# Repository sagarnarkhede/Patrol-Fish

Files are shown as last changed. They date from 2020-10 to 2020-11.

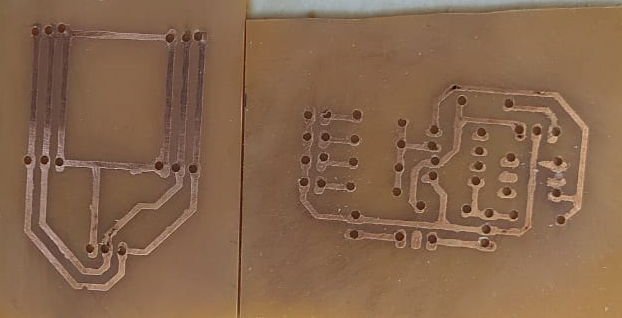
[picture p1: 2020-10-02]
Photos/Buoys_PCB.png

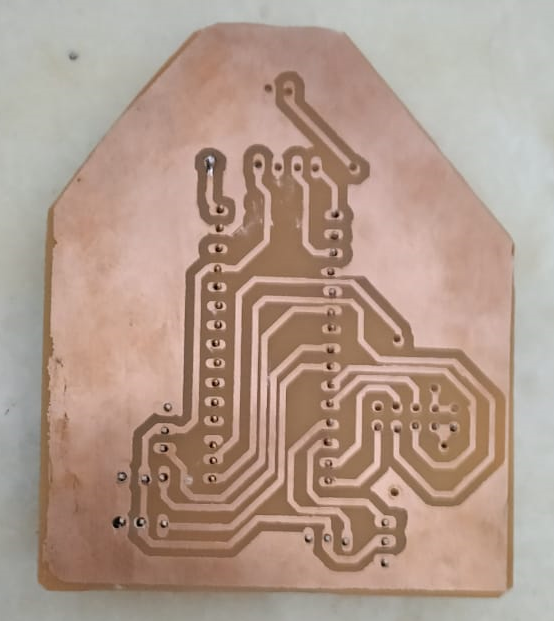
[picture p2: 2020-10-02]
Photos/PatrolFishp_PCB.png

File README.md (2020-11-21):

# Patrol-Fish
This is the theme of eYantra Robotics Competition 2019-20 held at IIT Bombay.The project was based on various skills like 3D Modelling of Fish, Wireless Communication,Waterproofi ng, programing of arduino etc I was participated in this competition and I worked as a team leader of our team. and we got rank 3.

<!--
## Team Members:-
### 1) [Sagar S Narkhede](https://www.linkedin.com/in/sagar-narkhede-5bb944195/)(Team Leader)
### 2) [Omkar Sutar](https://www.linkedin.com/in/omkarsutar8991/)
### 3) [Ashlesha Borade](https://www.linkedin.com/in/ashlesha-borade-719434162/)
### 4) [Pooja Katkar](https://www.linkedin.com/in/pooja-katkar-a85b6b137/)

-->

## Videos:-

[Final demostratio video](https://youtu.be/UlDN9iitq78)

[3D animation](https://youtu.be/h_NEuzW5vi0)

[theme intro](https://youtu.be/WjUetfCpf9E)

[progress video](https://youtu.be/jCL4euYWsCw)

[buyo testing](https://youtu.be/ekcvl8QJEpc)

[joystick testing](https://youtu.be/XAv6_P2s71k)

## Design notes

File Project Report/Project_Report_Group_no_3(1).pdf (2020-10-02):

A

## Project Report

On

# Aquatic FishRobo

### Guided by

Dr.N.P.Futane

### Submitted By

### 1. Sagar Sopan Narkhede (17231014) 2. Omkar Gorakhnath Sutar (16132063) 3. Pooja Kisan Katkar(17231011) 4. Ashlesha Maruti Borade (16131036)

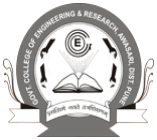
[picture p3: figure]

Department of Electronics and Telecommunication Engineering

## GOVT. COLLEGE OF ENGINEERING AND RESEARCH

## AWASARI (KHURD), DIST- PUNE 412405

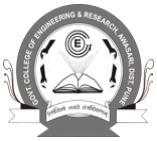
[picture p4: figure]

# CERTIFICATE

## This is to certify that following students of B.E. (Electronics and

## Telecommunication), have done bonafide work on the project stage-I

entitled – “AQUATIC FISHROBO”.

## They are allowed to submit this work to the Savitribai Phule Pune

## University towards partial fulfilment of the requirement for the award

## of Bachelor of Engineering (Electronics and Telecommunication)

during the year 2019-2020.

### 1. Sagar Sopan Narkhede (17231014) 2. Omkar Gorakhnath Sutar (16132063) 3. Pooja KisanKatkar (17231011) 4. Ashlesha Maruti Borade (16131036)

Project Guide | Head of Dept. | Principal
(Dr. N.P. Futane) | (Dr.M.S. Nagmode) | (Dr. A.S. Pant)

## INDEX

Sr. No | Table of contents | Page No
1 | Abstract | 4
2 | Introduction | 5
3 | Literature review | 7
4 | Hardware | 9
| 1.Electronic System | 10
| 2.Mechanical system | 15
5 | Joystick | 17
6 | PCB fabrication | 18
7 | Software | 21
8 | Algorithm | 23
9 | Flowchart | 24
10 | Program | 25
11 | Cost Estimation | 26
12 | Advantages | 27 28
13 | Applications
14 | Future scope | 28
15 | Conclusion | 29

ABSTRACT

In the Swachh Ganga mission getting data about the health of the water body, i.e. the

measurement of concentration of impurities, temperature etc is essential for creating a more

effective plan of action. In this project we unleash our imagination and discover our talent in

3D designing to build a bio-inspired fish robot that is capable of traversing in water to collect

data about a water-body's health and transmit it to a buoy. Challenges in this project include:

3D designing and fabrication, PCB designing, Microcontroller programming, wireless

communication etc.

INTRODUCTION

- The Ganges (or Ganga), the largest river in India, provides water to about 40% of

India's population across 11 states, serving an estimated population of 500 million

people with more than any other river in the world.

- But this source of life now severely polluted with human waste and industrial

contaminants, poses significant threats to human health and the larger environment.

- As engineers , what can we do to help in the Swachh Ganga mission. We know,

monitoring the state of a system is an essential part of trying to get it to a desired

target

- . In the Swachh Ganga mission getting data about the health of the water body, i.e. the

measurement of concentration of impurities, temperature etc is essential for creating a

more effective plan of action.

- In this project we unleash our imagination and discover our talent in 3D designing to

build a bio-inspired fish robot that is capable of traversing in water to collect data

about a water-body's health and transmit it to a buoy.

- Challenges in this project include: 3D designing and fabrication, PCB designing,

Microcontroller programming, wireless communication etc.

- In this project, the Aquatic Robot designed by the us needs to swim through a defined

course and trigger “Anchored Buoys” on its way. The course is defined by the

position and orientation of“Gateways”. We also designed a wireless joystick to

control the Aquatic Robot.

### Arena Configuration:

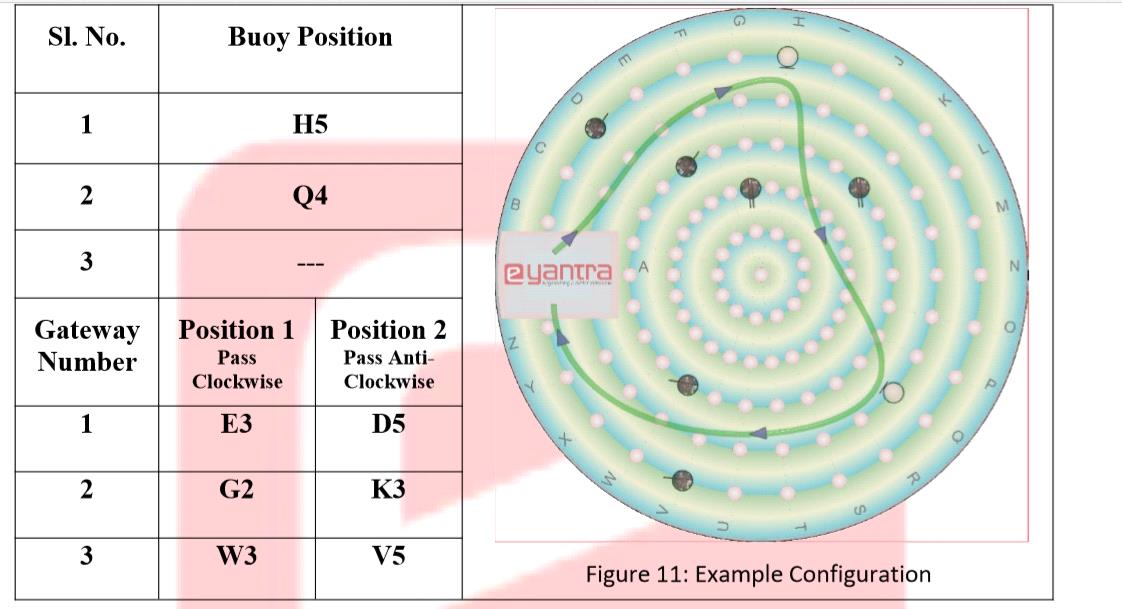
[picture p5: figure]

Figure: Arena Configuration.

LITERATURE REVIEW

The Ganges (or Ganga), the largest river in India, provides water to about 40% of

India's population across 11 states, serving an estimated population of 500 million people

with more than any other river in the world. But this source of life now severely polluted with

human waste and industrial contaminants, poses significant threats to human health and the

larger environment. As engineers , what can we do to help in the Swachh Ganga mission. We

know, monitoring the state of a system is an essential part of trying to get it to a desired

target. In the Swachh Ganga mission getting data about the health of the water body, i.e. the

measurement of concentration of impurities, temperature etc is essential for creating a more

effective plan of action. In this theme we unleash our imagination and discover our talent in

3D designing to build a bio-inspired fish robot that is capable of traversing in water to collect

data about a water-body's health and transmit it to a buoy. We divide the Project into a

number of tasks to build the Aqaurit Robot in a step- by-step manner making the process

more interesting for us. Challenges in this Project include: 3D designing and fabrication, PCB

designing, Microcontroller programming, wireless communication etc. We tiik inspiration

from the variety of fishes in the aquatic world and created the locomotion of that fish while

designing their robot. After building the bot,we need to navigate it in an arena.

The reference used for the microntroller boards and their specifications are:

- Arduino Nano (ATmega328)

The Arduino Nano is a small, complete, and breadboard-friendly board based on the

ATmega328P; it offers the same connectivity and specs of the Arduino Uno board in a

smaller form factor.[1][2] The Arduino Nano is programmed using the Arduino Software

(IDE), Arduino.cc's Integrated Development Environment common to all our boards and

running both online and offline.

- Arduino Nano(ATmega328P) technical specification
SRNO | COMPONENT | SPECIFICATION
1 | Microcontroller: | ATmega328
2 | Architecture: | AVR
3 | Operating Voltage: | 5 V
4 | Flash Memory | 32 KB of which 2 KB used by bootloader
5 | SRAM | 2 KB
6 | Clock Speed | 16 MHz
7 | Analog IN Pins | 8
8 | EEPROM | 1 KB
9 | DC Current per I/O Pins | 40 mA (I/O Pins)
10 | Input Voltage | 7-12 V
11 | PWM Output | 6
12 | Power Consumption | 19 mA
13 | PCB Size | 18 x 45 mm

HARDWARE

❖ ROBOT

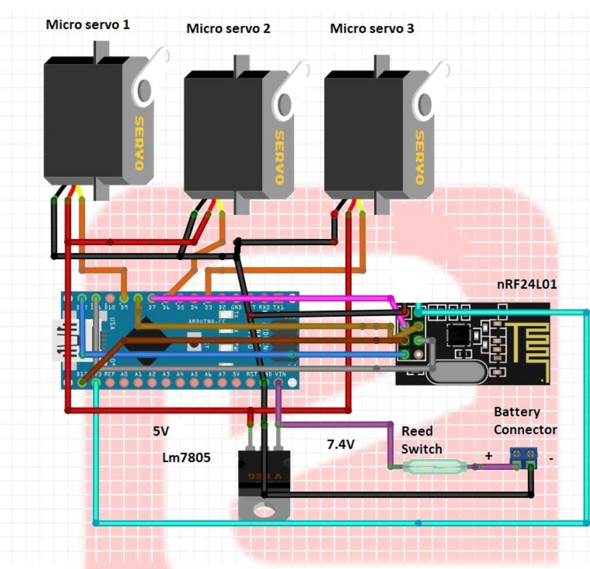
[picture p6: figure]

1.Electronic system:

### 1.1 Arduino Nano 328

The controller performs the various controlling actions & manages communication between

different units of system like sensors, actuators, motor driver, etc. for data analysis & further

operation.

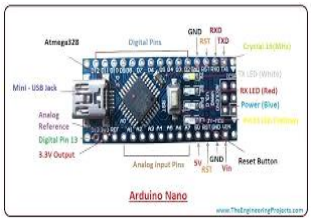
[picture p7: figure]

### 1.2 Joystick:

We have designed the joystick module to control the Aquatic Robot wirelessly.

Grove - Thumb Joystick is a Grove compatible module which is very similar to the 'analog'

joystick on PS2(PlayStation 2) controllers. The X and Y axes are two ~10k potentiometers

which control 2D movement bygenerating analog signals. The joystick also has a push button

that could be used for special applications.

When the module is in working mode, it will output two analog values, representing two

directions.Compared to a normal joystick, its output values are restricted to a smaller range

(i.e. 200~800), only when pressed that the X value will be set to 1023 and the MCU can

detect the action of pressing

1.3Servo Motor:

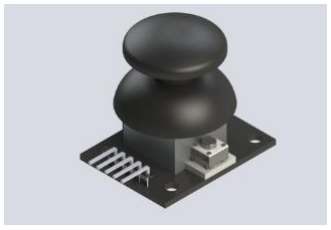
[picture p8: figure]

A servomotor is a rotary actuator or linear actuator that allows for precise control of angular

or linear position, velocity and acceleration. It consists of a suitable motor coupled to a sensor

for position feedback. It also requires a relatively sophisticated controller, often a dedicated

module designed specifically for use with servomotors.

Using these Servo motors we will give motion to our Aquatic Robot like fish.

The Towerpro MG90S Mini Digital Servo is 360° rotation servo. It is a Digital Servo Motor

which receives and processes PWM signal faster and better. It equips sophisticated internal

circuitry that provides good torque, holding power, and faster updates in response to external

forces.The good optimized performance and reliability of our servos have made them the

favourite choice of many RC hobbyists.

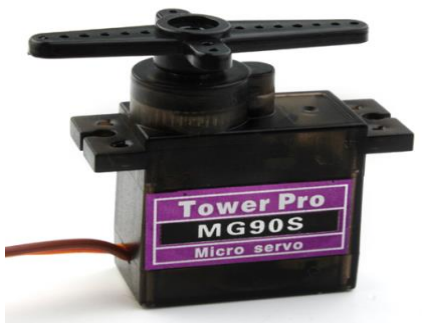
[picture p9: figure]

### 1.4 Li-ion Battery (2200 mAh, 11V):

To supply the power for the different units of the robot.This battery pack is made up of best

quality tested ICR 18650 2000mAh 20C Lithium-Ion Batteries and BMS circuit. It is small

in size and weight compared to Ni-Cd, Ni-MH, and Lead Acid Batteries. With the inbuilt

Charge protection circuit, the battery pack can be directly charged with the DC power

Adapter, so need not use the specialized battery chargers and worry about overcharging.

We build these battery packs in diverse range to fulfil 7.4V to 14.8 V and differential

capacity requirement. This battery pack is very convenient to recharge and install in your

project requirement with 5mm DC female jack for changing and Nylon Female T-connector

for discharging or connecting to your applications.

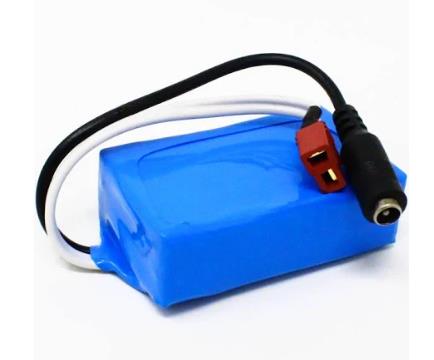
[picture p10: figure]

### 1.5 NRF24L01 Transceiver

The nRF24L01+ is a single chip 2.4GHz transceiver with an embedded baseband protocol

engine (Enhanced ShockBurstTM), suitable for ultra low power wireless applications. The

nRF24L01+ is designed for operation in the world wide ISM frequency band at 2.400 -

2.4835GHz. You can operate and configure the nRF24L01+ through a Serial Peripheral

Interface (SPI). The register map, which is accessible through the SPI, contains all

configuration registers in the nRF24L01+ and is accessible in all operation modes of the chip.

The radio front end uses GFSK modulation. It has user configurable parameters like frequency channel, output power and air data rate. nRF24L01+ supports an air data rate of

250 kbps, 1 Mbps and 2Mbps. The high air data rate combined with two power saving modes

make the nRF24L01+ very suitable for ultra low power designs.nRF24L01+ is drop-in

compatible with nRF24L01 and on-air compatible with nRF2401A, nRF2402, nRF24E1 and

nRF24E2. Intermodulation and wideband blocking values in nRF24L01+ are much improved

in comparison to the nRF24L01 and the addition of internal filtering to nRF24L01+ has

improved the margins for meeting RF regulatory standards. Internal voltage regulators ensure

a high Power Supply Rejection Ratio (PSRR) and a wide power supply range.

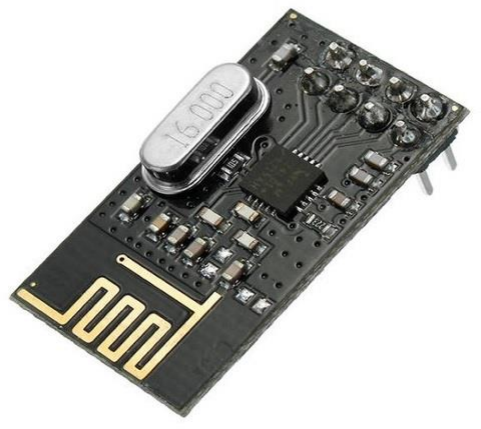
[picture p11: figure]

### 1.6 Reed Switch:

This is a small device called a reed switch. When the device is exposed to a magnetic

field, the two ferrous materials inside the switch pull together and the switch closes.

When the magnetic field is removed, the reeds separate and the switch opens. This makes

for a great non-contact switch. This switch can carry up to 1.2A.

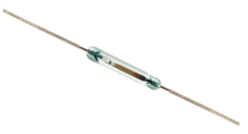
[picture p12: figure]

### 1.7 Hall Effect Sensor:

A Hall effect sensor is a device that is used to measure the magnitude of a magnetic

field. Its output voltage is directly proportional to the magnetic field strength through

it.Hall effect sensors are used for proximity sensing, positioning, speed detection, and

current sensing applications.Frequently, a Hall sensor is combined with threshold

detection so that it acts as and is called a switch. They can also be used in computer

keyboards, an application that requires ultra-high reliability. Another use of a Hall

Sensor is in the creation of MIDI organ pedal-boards, where the movement of a 'key'

on the pedal-board is translated as an on/off switch via Hall Sensors.

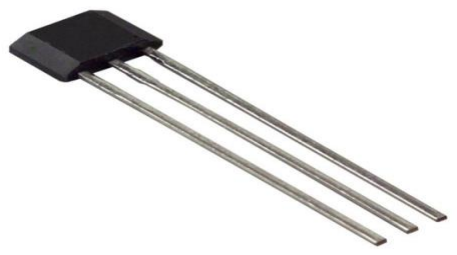
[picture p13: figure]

2.Mechanical system

### 2.1 Servo Motor:

Servo motor is used for giving "S" motion to the fish Robot. There are 5 Servo motor used

1.Head Servo: which will control middle part.

2.Two Fin Servo: To control Fin motion

Middle Servo: To control second part

Tail Servo: To control Tail of the Fish

2.2 3D Printed Fish:

It is the hardware body structure of the robot to constrain all the components required for the

robot. For the fabrication of Nylon 6 (PA6/66)

A filament that is ideal for more experienced users of 3D printers. Nylon is strong and

durable. Nylon can be used as flexible hinge when printed thinly or can be strong enough to

use for engineering applications such as gears due to low friction qualities and where subject

to low force loadings. A heated print bed is recommended when printing with Nylon to

prevent warping. Our Nylon is made using the purest raw materials without fillers. Our

crosssectional roundness is consistent throughout the whole spool to ensure that a reliable

printing experience is achieved over repeated prints. Our filaments are free from air bubbles

or voids that help to ensure accurate and high definition printing results.

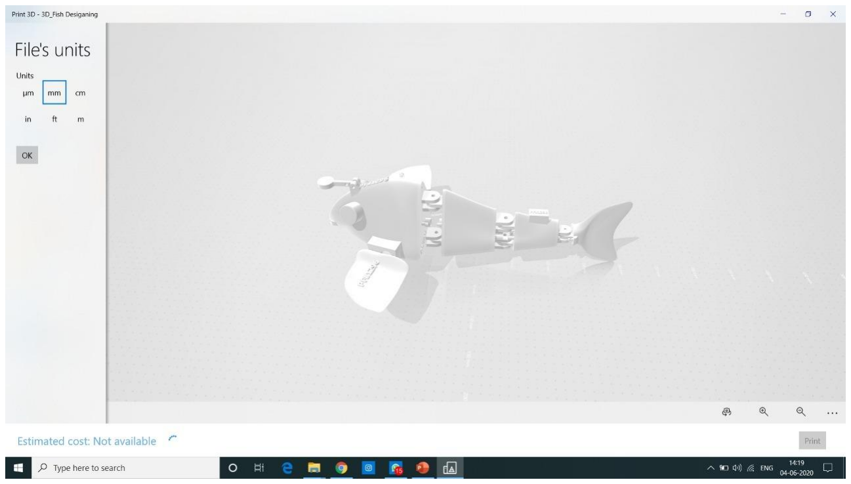
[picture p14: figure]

2.3Gateways:

The pair of objects that the Aquatic Fish Robot needs to go through in the assigned sequence

and also in the direction specified. Dimension of the cylinder are 70mm ± 5mm in diameter

and 170mm in height.

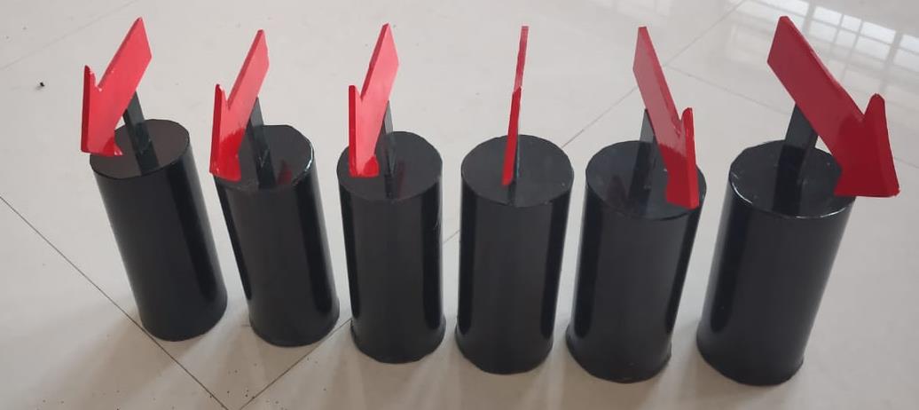
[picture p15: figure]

### 2.4 Anchored Buoys:

The object the Aquatic Fish Robot needs to trigger. The Anchored Buoy is a structure to be placed on

the floor of the pool.The structure has two major parts: Tower that indicate when the Patrol Fish robot

triggers | the | sensor. | The | dimension | of | the | cylinder | of the | Buoy | is | 70mm | ±

5mmindiameterand170mminheight.A circuit board in the tower of the buoy has a latch circuit that

switches the LEDs ON as soon as hall effect sensors senses the field of the magnet on the Patrol Fish

and leaves it on for the rest of the run.

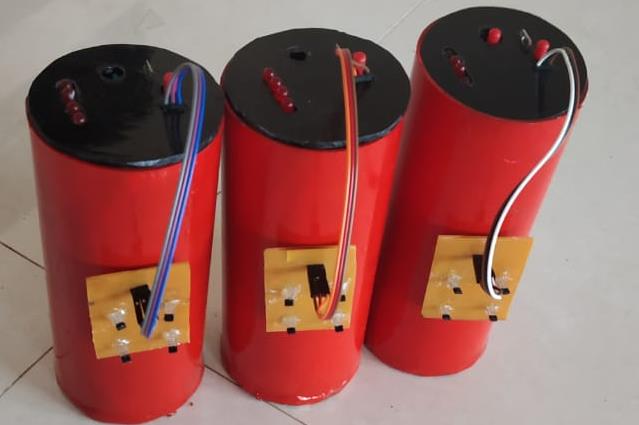
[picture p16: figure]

JOYSTICK

- Description:

1.PCB design forWireless Joystick and hall effect sensor:

We have designed a PCB for Wireless Joystick in Eagle software.

Required Hardware for Wireless Joystick:

1. ArduinoNanoboard
2. NRF24L01Transceiver
3. Joystickmodule
4. Connectors

Joystick module

The Joystick is nothing but two potentiometers that allow us to measure the movement of the

stick in 2-D. Potentiometers are variable resistors and, in a way, they act as sensors providing

us with a variable voltage depending on the rotation of the device around its shaft.(source)

Buzzer:

Buzzer Module for Arduino is an audio signaling device. Buzzer rings out as long as it

receives signal in its data pin.

- Connecting Hardware for Wireless Joystick (Transmittersystem):

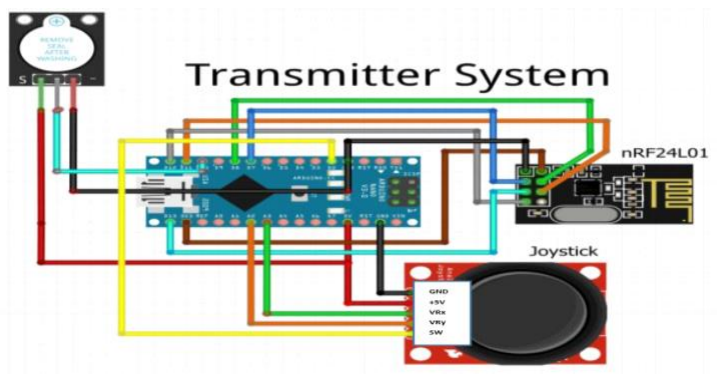
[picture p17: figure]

Figure: Transmitter System connections

PCB FABRICATION

Printed Circuit Board(PCB)

PCB are mainly classified into two types:

Through Hole : Through-hole technology is the process by which component leads

are placed into drilled holes on a bare PCB. Through-hole components are best used for

high-reliability products that require stronger connections between layers.

Surface mount: In Surface Mount Technology components are secured only by

solder on the surface of the board. An SMT component is usually smaller than its through-

hole counter part because it has either smaller leads or no leads at all.

- PCB fabrication.

Step1: Printing the board design file:

After completion of PCB board design file, from board file open visibility settings

by clicking on the button on the top left of the screen. Make only the “Bottom”,

“Pads” and “Dimension” layers visible and hide all other layers

Step2: Toner Transfer:

Cut the copper clad of the approximate size of your board file. Place the printed

photographic paper on copper clad and start pressing it with a heated iron

Step3: Etching process:

Take water in a small plastic container. Add small amount of ferrous chloride

solution to it. Place the toned board in the solution as Stir the board in the

solution.Untoned part will start etching.

Step4:Cleaning:

After etching wash the board with water. Use acetone to remove the toned paper and

marker pen ink

Step5:Drilling:

Drill the holes for pads

Step6: Testing:

Check the continuity test of all the tracks by mustimeter. Removetheshortedtracks.

Step7: Soldering:

Place the component at the top board of the board and start soldering it to the

track with solder wire.

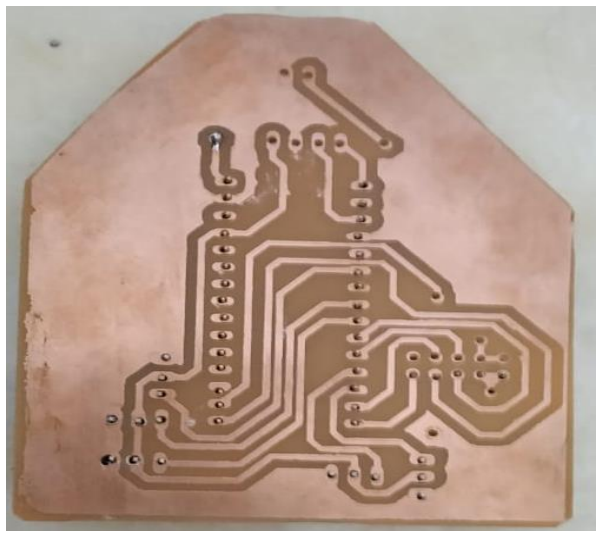
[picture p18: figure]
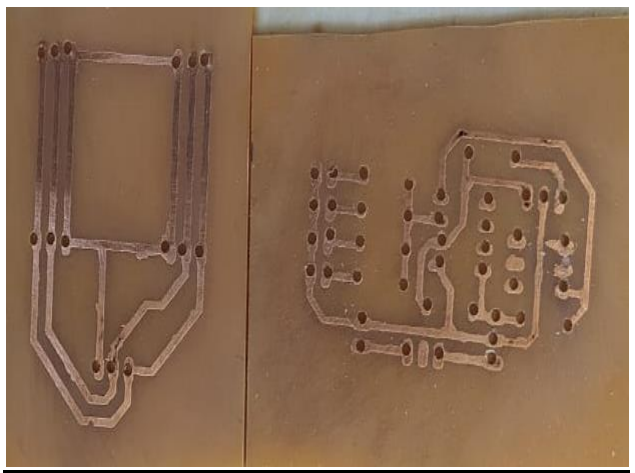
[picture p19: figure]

- Waterproofing:

1.Waterproofing the Fish Body:

Waterproofing of the joints of the Fish body is done by using,

1.Candle Wax

2.Balloons

3.Silicone Gel

### 2. Waterproofing the Elctronic Components:

1. Nail Polish Coating
2. Silicone paste/Adhesive

SOFTWARE

- Blender:

Blender is the free and open source 3D creation suite. It supports the entirety of the 3D

pipeline—modeling, rigging, animation, simulation, rendering, compositing and motion

tracking, even video editing and game creation. Advanced users employ Blender’s API for

Python scripting to customize the application and write specialized tools; often these are

included in Blender’s future releases. Blender is well suited to individuals and small studios

who benefit from its unified pipeline and responsive development process.

- Arduino IDE:

The Arduino Integrated Development Environment (IDE) is a cross-platform application (for

Windows, macOS, Linux) that is written in functions from C and C++. The Arduino IDE

supplies a software library from the Wiring project, which provides many common input and

output procedures. User-written code only requires two basic functions, for starting the sketch

and the main program loop, that are compiled and linked with a program stub main() into an

executable cyclic executive program with the GNU toolchain, also included with the IDE

distribution..

- Autodesk Fusion 360:

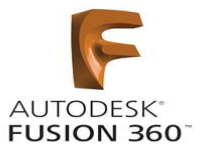
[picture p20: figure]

Fusion 360 is a cloud-based 3D CAD, CAM & CAE design tool from Autodesk. It is

available on a number of platforms including Windows, Mac & In-Browser. It is

functionally similar to other 3D software like Solidworks, Siemens NX, Inventor or Catia.

It is a very full featured program and is available to hobbyists and start-up businesses for

no cost.

- Eagle:

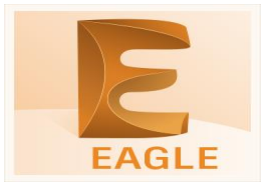
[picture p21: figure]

Acronym for Easily Applicable Graphical Layout Editor, is a design software by Cadsoft

Computers. It is widely used by educationalists, students, hobbyists and professionals

because of its rich yet simple interface with large component library cross-platform support

on Windows, Mac and Linux too! EAGLE is a scriptable electronic design

automation (https://en.m.wikipedia.org/wiki/Electronic_design_automation) (EDA) application with schematic capture, (https://en.m.wikipedia.org/wiki/Schematic_capture) printed circuit

board (https://en.m.wikipedia.org/wiki/Printed_circuit_board) (PCB) layout, (https://en.m.wikipedia.org/wiki/PCB_layout) auto-router (https://en.m.wikipedia.org/wiki/Auto-router) and computer-aided manufacturing (https://en.m.wikipedia.org/wiki/Computer-aided_manufacturing) (CAM) features.

ALGORITHM

1.Start

2. Trigger the Aquatic Robot using Magnet .It will turn the Robot on.
3. Now turn the Joystick too.
4. Establish the NRF Connections Properly and indicate it by glowing LED on Joystick.
5. Use Joystick to Send the Character Massage to NRF Reciever with the Encoded Servo

Action.

6. After receiving the Text properly servo motor will move as per given angle in the Script.
7. Each Joystick value of X and Y will give each servo different Angles and Fish will get its

motion.

8. .Using the Joystick Control the Fish in Water.

9.Pass the Robot safely through the the Gateways.

10. Trigger the Boys with the Magnet on the Robot using Hall effect Sensor.
11. Repeat 9 and 10 until Robot reaches at the Start point again.
12. End

FLOWCHART

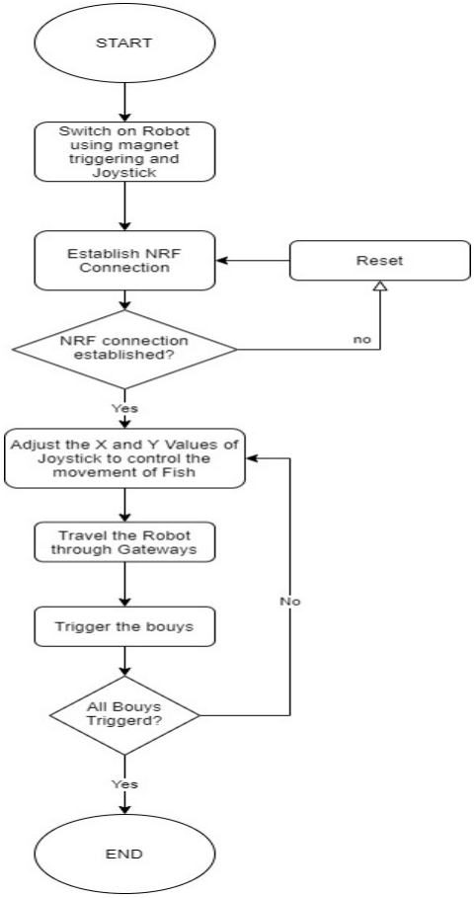
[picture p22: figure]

PROGRAM

### https://drive.google.com/drive/folders/1aHHeiEQJljIpSD1Fyj1P6sBwNRnK6c_

_?usp=sharing (https://drive.google.com/drive/folders/1aHHeiEQJljIpSD1Fyj1P6sBwNRnK6c__?usp=sharing)

COST ESTIMATION

Sr No . | Name of Components | Quantity | Unit Cost(Rs) | Total
1 | Arduino Nano (ATmega 328 Controller) | 2 | 1563 | 1563
2 | NRF24L01 | 2 | 220 | 440
3 | Joystick Module | 1 | 75 | 75
4 | Buzzer Module | 2 | 20 | 40
5 | Servo Motor | 5 | 195 | 975
6 | Battery(5V) | 4 | 25 | 100
7 | Battery(9V) | 2 | 470 | 940
8 | Reed Switch | 1 | 15 | 15
9 | Slide Switch | 3 | 64 | 192
10 | Magnet | 2 | 15 | 30
11 | Push Button | 7 | 15 | 105
12 | Timer IC555 | 3 | 225 | 675
13 | Hall Effect Sensor | 27 | 20 | 540
14 | LEDs | 20 | 5 | 100
15 | Capacitors | 10 | 5 | 50
16 | Resistors | 10 | 3 | 30
17 | Programming cable | 2 | 180 | 360
18 | IC7805 | 2 | 12 | 24
19 | IC7809 | 2 | 12 | 24
20 | IC7812 | 1 | 12 | 24
21 | Water Pool | 1 | 1500 | 1500
22 | Arena | 1 | 1300 | 1300
23 | 3D Printing material | 1kg | 1400 | 1400
| Total | | | 10502

ADVANTAGES

- Aquatic Robots are used for research about animals and underwater wildlife.
- Underwater Exploratory Robots can go underwater longer and deeper than humans
- Robots are less likely to get hurt or die on any missions.
- Exploratory robots can gain information that we can’t physically obtain.

FUTURE SCOPE AND APPLICATIONS

1. Submarine wireless communication.
2. 3D Game Design Platform.
3. Creating Animated movies.
4. Macrolevel Research on Aquatic life and habitat.

CONCLUSION

The project “Aquatic Fish Robot” includes the implementation bio-inspired robot that is

capable of traversing in water .This project includes the implementation of various concepts in

real time based applications like 3D gaming, 3D animation . The project presents a complete

3D non-linear dynamic model of a biomimetic robotic fish. In this project we done with 3D

designing and fabrication, PCB designing and fabrication, Microcontroller programming,

wireless communication etc.

REFERENCES

- eYANTRA Sponsored by MHRD (https://mhrd.gov.in/hi/node/2356) under the National Mission on Education through

ICT (https://mhrd.gov.in/technology-enabled-learning-0) program. An initiative by IIT Bombay that aims to create the next generation of

embedded systems engineers with a practical outlook to help provide practical

solutions to some of the real world problems.

https://www.e-yantra.org

- Autodesk Fusion 360 Tutorials:

https://www.autodesk.in/products/fusion-360/learn-support

- Languages :

Arduino IDE: https://www.arduino.cc/en/Tutorial/HomePage?from=Main.Tutorials

- https://easyengineering.net/microprocessor-and-microcontroller-system-by-godse/
- Book on Programming and Interfacing ATMEL's AVRs
•
- Software source

Audesk Fusion 360:

https://www.autodesk.in/campaigns/education/fusion-360?mktvar002=3510851|SEM|GGL_AEX_Fusion-360_APAC_IN_Visits_SEM_BR_New_EX_INQ_3510851_General-Fusion___&gclid=CjwKCAjwt-L2BRA_EiwAacX32ZG_SE8pQGPt72UA9roErpKd1DpoRIBKnX3Hd71v8YmvZIbXKzqOHhoCEfoQAvD_BwE (https://www.autodesk.in/campaigns/education/fusion-360)

- Autodesk Eagle:

https://www.autodesk.in/products/eagle/free-download

- Sensors and actuators kit

https://robu.in/product/arduino-37pcs-sensor-kit-set/

- e-Yantra Lab Setup Initiative

https://www.e-yantra.org/elsi

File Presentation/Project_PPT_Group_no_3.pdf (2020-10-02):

PRESENTATION

ON

# Aquatic FishRobo

❖ Presented by:
1.Sagar Narkhede(17231014) | 3. Ashlesha Borade(16131036)
2.Omkar Sutar (16132063) | 4. Pooja Katkar(17231011)

❖ Guided by:
Dr.N.P. Futane

❖ Reference by:
eYantra Robotics Competition

In this theme, we are designing and building a Aquatic FishRobo that bio-mimics different locomotion's of a fish. The aquatic world is populated with a diverse variety of fishes from which we took inspiration for designing our Aquatic robot. This robot replicates the natural movement of a fish’s muscles by using a number of servo actuated joints that are connected to each other. Through a coordinated movement of these joints, the fish robot can swim to propel itself forward.
In order to represent the muscle joints of a natural fish, we use servo actuators and for the fish’s body, we design brackets, that serve the following two purposes:
to define the relative position and orientation between actuators and
to define the profile of the fish.

### 1. Introdction:

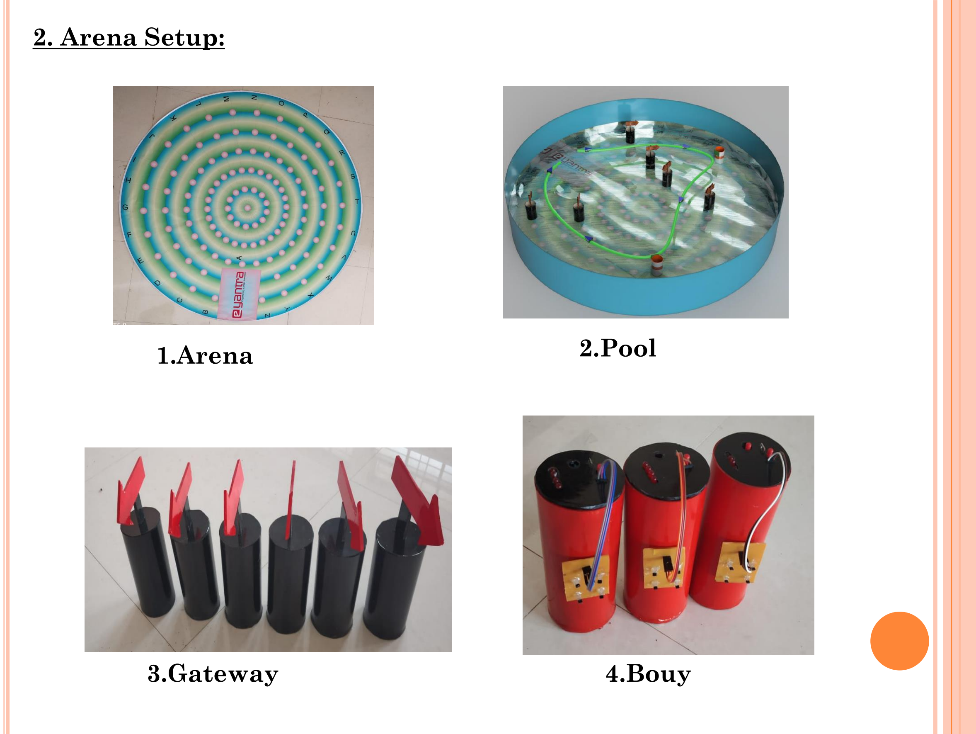
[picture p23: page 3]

### 2. Arena Setup:

1.Arena | 2.Pool
3.Gateway | 4.Bouy

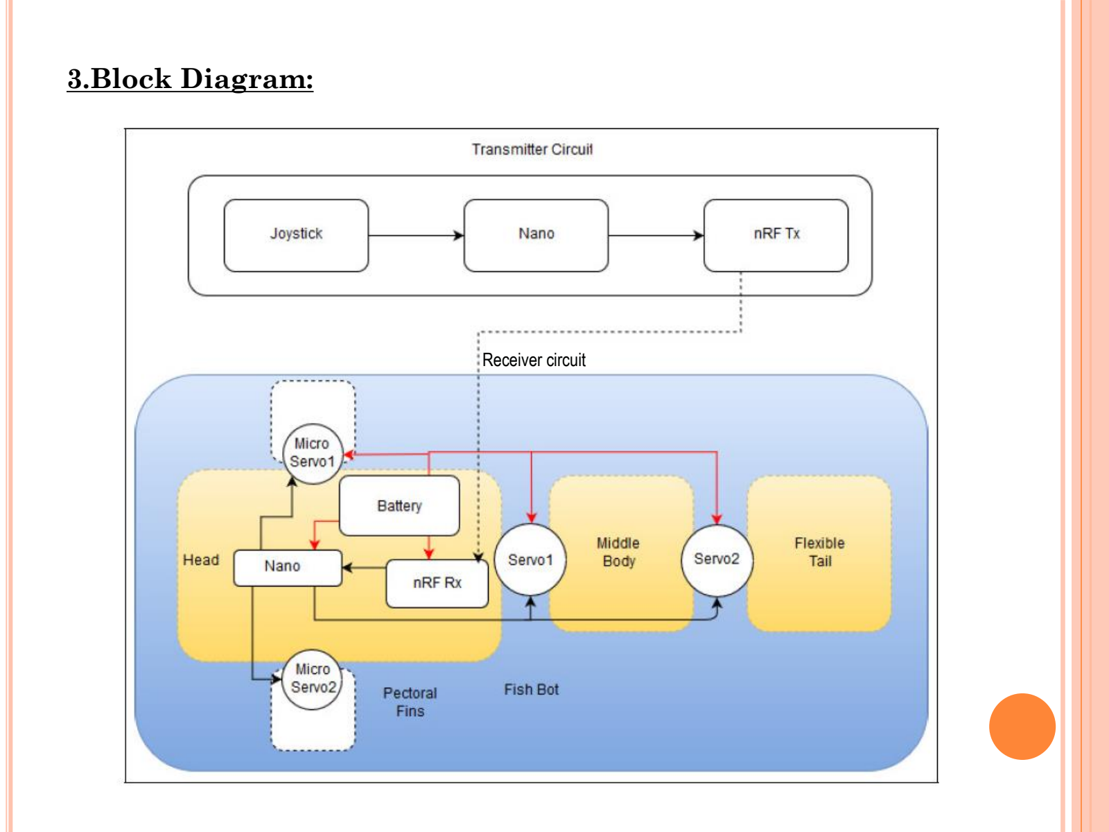
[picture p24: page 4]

3.Block Diagram:

Receiver circuit

4.Connection diagram:

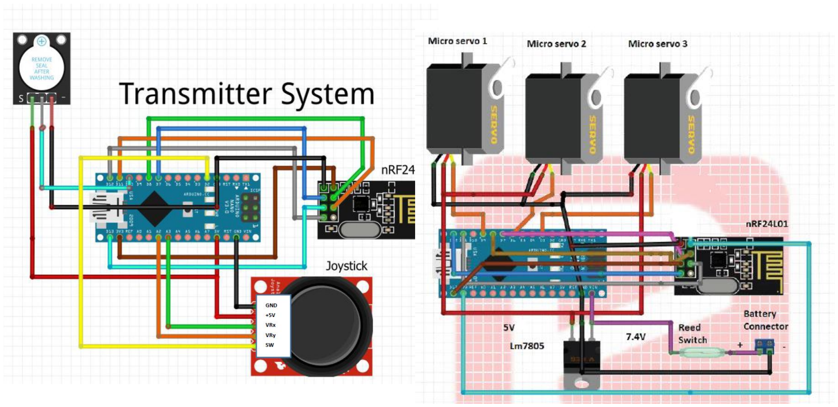
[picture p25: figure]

1.Transmitter System | 2.Receiver System

5.Challenges:

1. 3D designing and fabrication.
2. 3D Animation using Blender Software.
3. 3D Gaming using key controlled.
4. PCB designing and Fabrication.
5. Microcontroller programming
6. Wireless communication.
7. Waterproofing.

### 7.1 Waterproofing the Electronics:

Nail Polish Coating
Silicone Paste/Adhesive

### 7.2 Waterproofing of Fish:

Custom Silicon Gasket using a 3D Printed Mould and Liquid Silicone Rubber.
Candle Wax near the circular joints.
Waterproof duct tape.

6.Hardware:

Components | Quantity
Arduino Nano(Atmega328 Controller) | 2
NRF24L01 | 2
Joystick Module | 1
Buzzer Module | 2
Servo Motors | 5
Batteries | 5, 9v
Reed Switch | 1
Slide Switch | 5
Magnet. | 2
Components | Quantity
Push Button | 10
Timer Ic555 | 3
Hall Effect Sensor | 27
LEDs | 20
Capacitors & Resistor | _
Copper Clad | _
Programming Cable | 2
IC7805,7809,7812 | 5
Jumper Wire | _
PLA 3D Printing Material | 1kg

7.Software:

1.Autodesk Fusion 360:- 3D designing.

2.Autodesk eagle :- PCB Designing.

3.Arduino IDE`:- Programing the microcontroller.

4.Blender :- 3D Animation.

5. Latex :- For Documentation.

6.UBGE :- 3D Game using key controlled.

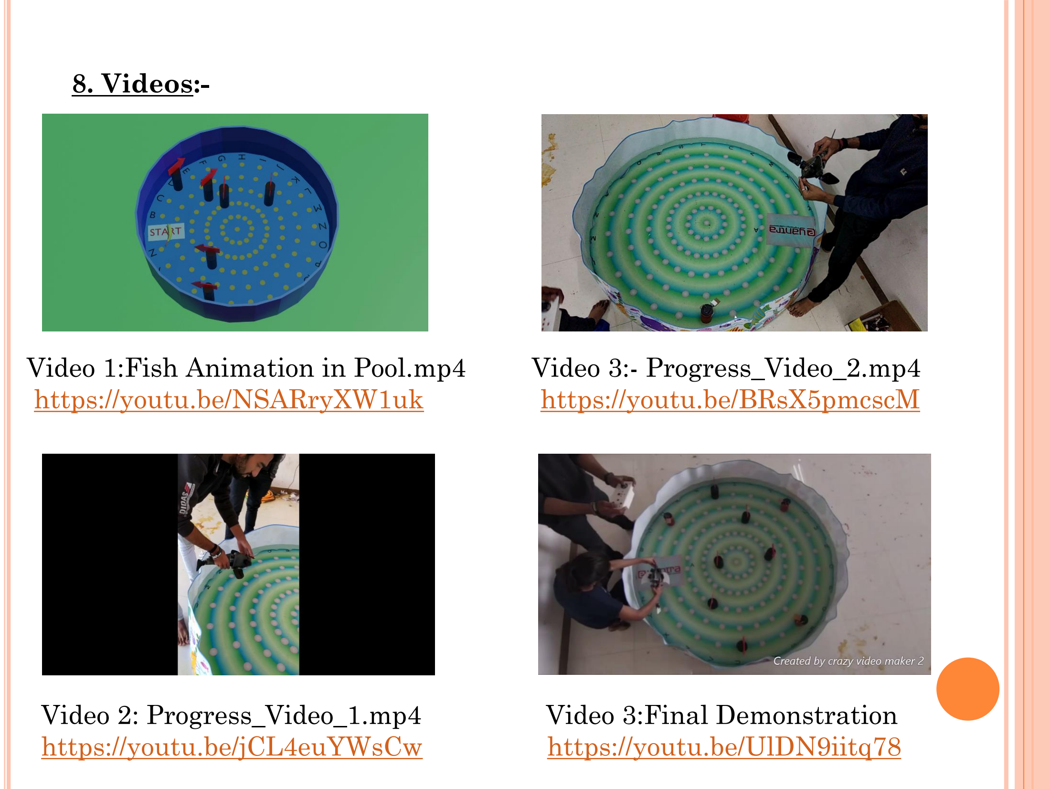
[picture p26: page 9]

### 8. Videos:-

Video 1:Fish Animation in Pool.mp4 | Video 3:- Progress_Video_2.mp4
https://youtu.be/NSARryXW1uk | https://youtu.be/BRsX5pmcscM
Video 2: Progress_Video_1.mp4 | Video 3:Final Demonstration
https://youtu.be/jCL4euYWsCw | https://youtu.be/UlDN9iitq78

9. 3D Fish Design using Autodesk Fusion 360


10. 3D Fish using Blender 2.82


11. 3D Arena Design using Blender 2.82


### 10. Application:

1.Submarine wireless communication.

2.3D Game Design Platform.

3. Creating Animated movies.
4. Macrolevel Research on Aquatic life and habitat.

# Thank you

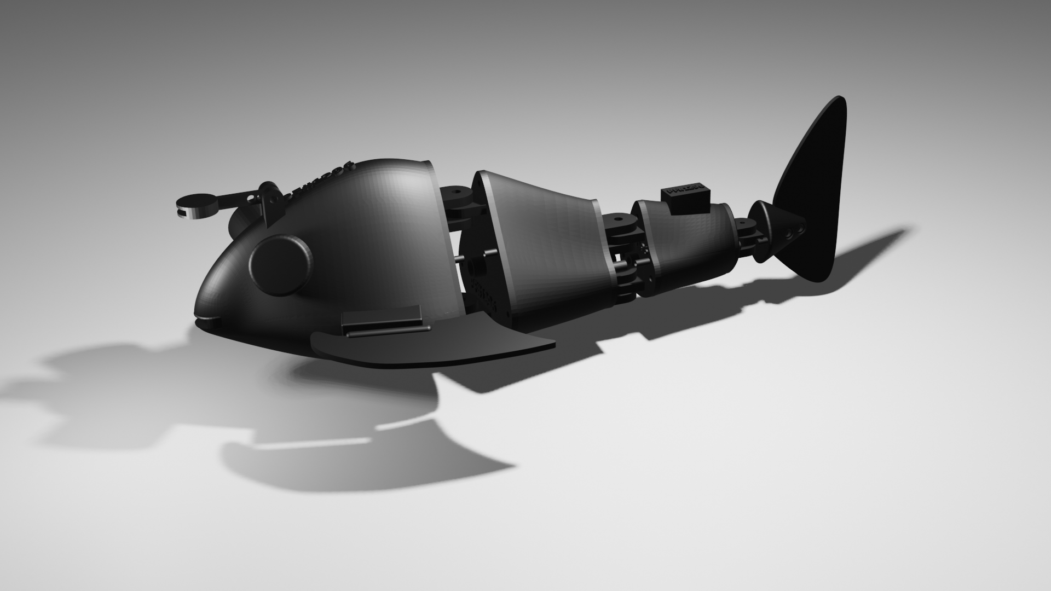
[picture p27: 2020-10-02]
Photos/Render Image_.png

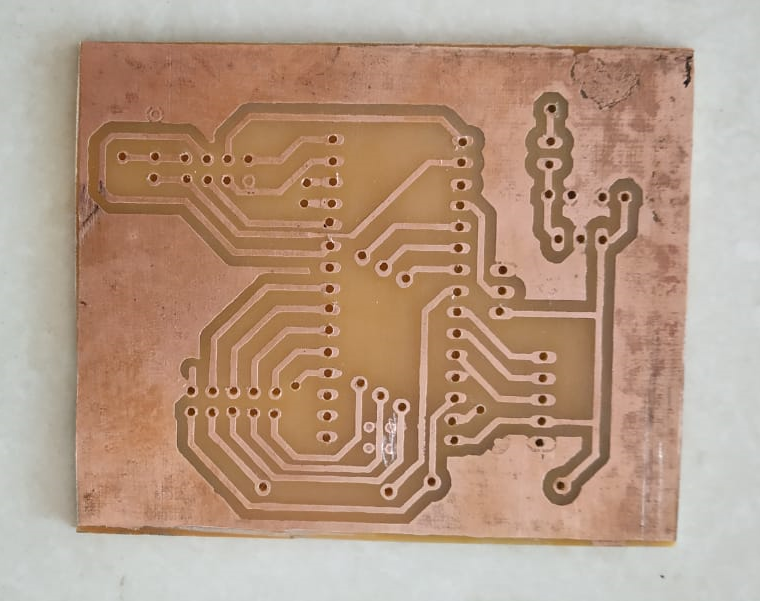
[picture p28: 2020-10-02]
Photos/JoystickBottom_PCB.png

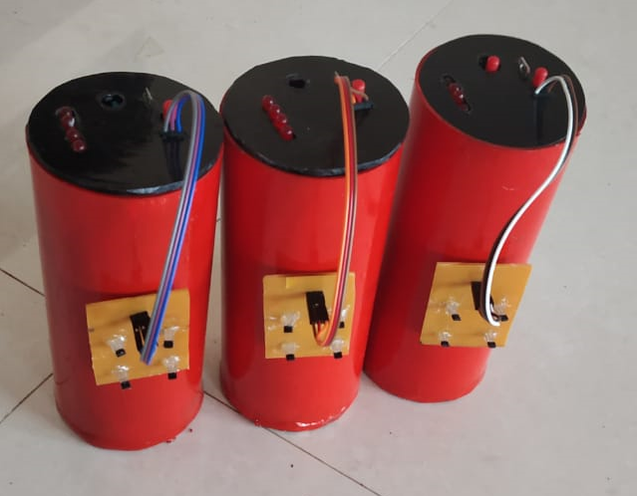
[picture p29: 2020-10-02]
Photos/Buoys.png

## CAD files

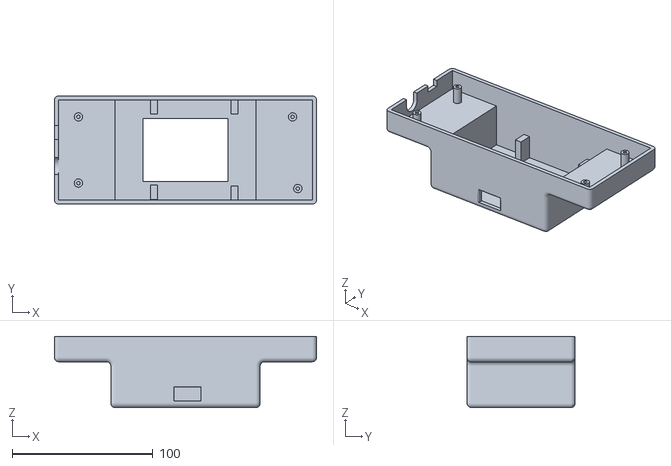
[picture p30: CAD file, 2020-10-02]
3D joystick model/bottom.stl
186.0 x 77.0 x 50.5

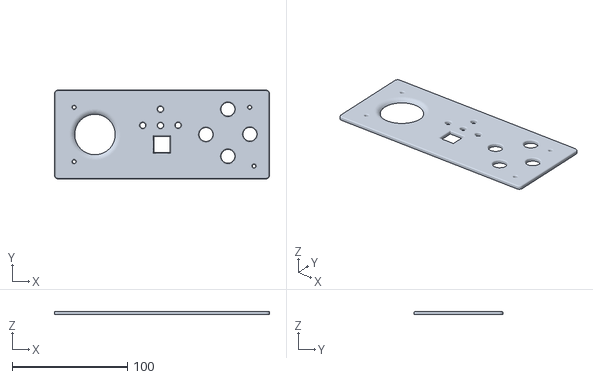
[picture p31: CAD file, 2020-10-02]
3D joystick model/Top.stl
186.2 x 76.8 x 3.00

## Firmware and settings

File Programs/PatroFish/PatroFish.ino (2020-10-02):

/*
  ▪ * Team Id: pf#1296
  ▪ * Author List: Sagar Narkhede, Omkar Sutar,Pooja katkar, Ashlesha Borade
  ▪ * Filename: receiver_code
  ▪ * Theme: Patrol Fish
  ▪ * Functions: void servo(char servo_no, int angle, int speed)
  ▪ * Global Variables:None
  ▪ *
  ▪ */

#include <SPI.h>
#include <nRF24L01.h>
#include <RF24.h>
#include <VarSpeedServo.h>
/*
VarSpeedServo myservo1; // left fin servo pin
VarSpeedServo myservo2; // right fin servo pin
*/VarSpeedServo myservo3; // head servo pin
VarSpeedServo myservo4; // middel servo pin
VarSpeedServo myservo5; // tail servo pin

RF24 radio(7, 8);// CE, CSN pins of the nRF24L01 module are connected to these pins [CE: Chip Enable, CSN: Chip Select Not]
const byte address[6] = "00001";//5 Byte address of nrf device

void setup()
{
  Serial.begin(9600);//Start serial communication port
  Serial.println("Rx Starting");//Print a line on serial monitor to indicate start of code.

  //***********  Initialize the nRF24L01 module ************************************************
  radio.begin();
  radio.openReadingPipe(0, address);
  radio.setPALevel(RF24_PA_MIN);
  radio.startListening();

  radio.setDataRate(RF24_250KBPS);
  //********************************************************************************************
  //attach the servo motors to pins 3, 5, 6 ,9,10 of Arduino Nano
  /*myservo1.attach(10);
  myservo2.attach(9);*/
  myservo3.attach(3);
  myservo4.attach(5);
  myservo5.attach(6);
  pinMode(A1, OUTPUT);
  pinMode(A0, INPUT);
}

void loop()
{

 
  
  if (radio.available())
  {
    char text[32] = ""; //initialize array to save input command from joystick
    radio.read(&text, sizeof(text));//read the command from joystic
    Serial.println(text);//print the command
    /*
       comapir the input data with the fix data and give the particular movement to the fish
    */
    if (text[0] == 'f' && text[1] == 'f')//take a forward motion
    {

     /* servo('l', 90, 250);
      servo('r', 90, 250);*/
      servo('h', 90, 100);
      servo('m', 30, 100);
      servo('t', 100, 100);
      delay(500);
      servo('m', 160, 100);
      delay(500);
      servo('m', 90, 100);
    }
    else   if (text[0] == 's' && text[1] == 'f')//take a forward motion
    {
      servo('h', 140, 200);
      servo('m', 40, 100);
      servo('t', 150, 250);
     /* servo('l', 90, 250);
      servo('r', 90, 250);*/
      delay(150);

      servo('h', 50, 200);
      servo('m', 130, 100);
      servo('t', 50, 250);
      delay(150);
      servo('h', 90, 100);
      servo('m', 90, 100);
      servo('t', 100, 100)  ;
    }

    else if (text[0] == 'l' && text[1] == 'l')//take a left motion
    {
      servo('h', 170, 200);
      servo('m', 30, 100);
      servo('t', 160, 250);
     /* servo('l', 90, 250);
      servo('r', 90, 200);*/
      delay(150);
      servo('t', 100, 250);
      delay(150);
    }

    else if (text[0] == 'r' && text[1] == 'r')//take a right motion
    {
     /* servo('l', 90, 250);
      servo('r', 90, 250);*/
      servo('h', 30, 200);
      servo('m', 160, 100);
      servo('t', 40, 250);
      delay(150);
      servo('t', 100, 250);
      delay(150);
    }
    else if (text[0] == 's' && text[1] == 's')//stop the robot
    {
   /*   servo('l', 90, 250);
      servo('r', 90, 250);*/
      servo('h', 90, 100);
      servo('m', 80, 100);
      servo('t', 100, 100);
      // delay(300);
    }
    else if (text[0] == 'w' && text[1] == 'd')//detect water
    {
      digitalWrite(A0, HIGH);//initialize the input pin
      int s = analogRead(A0); //read the status of input pin
      Serial.println(s);
      if (s <= 500)//comapire the input value with threshold
      {
        Serial.println(s);
        digitalWrite(A1, HIGH);//turn on the indicator
        delay(200);//wait for indication
        digitalWrite(A1, LOW);//turn off the indicator
        delay(200);//wait for indication
        s = analogRead(A0);
      }
      else
        digitalWrite(A1, LOW);//turn off  indication
    }
    else
      Serial.println("wrong data");
  }
  else
    Serial.println("conection_fail");
}

/*
    Function Name:void servo(char servo_no, int angle, int speed)
     Input:servo_no,angle,speed
     Output: none
     Logic: this function are use to reduse the complixity to apply the saperaty angle ,speed ,no of servos etc
     as per the example given below the head servo moveto 90 degree angle with speed 200
     Example Call: servo('h', 90, 200);
*/
void servo(char servo_no, int angle, int speed)
{
  switch (servo_no)
  {
    case 'l'://select left fine servo
     // myservo1.write(angle, speed); //move left fine servo to input angle with input speed
      break;
    case 'r'://select right fine servo
     // myservo2.write(angle, speed);//move right fine servo to input angle with input speed
      break;
    case 'h'://select head servo
      myservo3.write(angle, speed);//move head servo to input angle with input speed
      break;
    case 'm'://select middel servo
      myservo4.write(angle, speed);//move middel servo to input angle with input speed
      break;
    case 't'://select tail servo
      myservo5.write(angle, speed);//move tail servo to input angle with input speed
      break;
  }
}

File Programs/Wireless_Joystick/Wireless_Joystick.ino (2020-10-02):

/*
  ▪ * Team Id: pf#1296
  ▪ * Author List: Sagar Narkhede, Omkar Sutar,Pooja katkar, Ashlesha Borade
  ▪ * Filename: transmitter_code
  ▪ * Theme: Patrol Fish
  ▪ * Functions: void buzzer(),void read()
  ▪ * Global Variables:button_up,button_down,button_left,button_right
  ▪ *
  ▪ */
#include <SPI.h>
#include <nRF24L01.h>
#include <RF24.h>
#define joyX A6 // Horizontal axis Potentiometer of Joystick module
#define joyY A7  // Vertical axis Potentiometer of Joystick module
int button = A5;   // Button is connected to pin A5 of arduino
int buttonState = 0;  // variable to store value from the in-built push button in the joystick module
int buz = A0;//buzzer pin
int button_up;
int button_up1 = 2; //button for upword movement of fish
int button_down1 = 4;//button for downword movement of fish
int button_down;
int button_left1 = 3;//button for leftword movement of fish
int button_left;
int button_right1 = 5;//button for rightword movement of fish
int button_right;
int buzz = A0;//conect buzzer to A0 pin
int xValue = 0; // read the analog value of Horizontal axis Potentiometer
int yValue = 0; // read the analog value of Vertical axis Potentiometer
int fLED = A2;//LED for forward ditection indicator
int rLED = A1;//LED for right ditection indicator
int lLED = A4;//LED for left ditection indicator
int tLED = A3;//LED for transmision indicator
int count = 0;
RF24 radio(7, 8);// CE, CSN pins of the nRF24L01 module are connected to these pins [CE: Chip Enable, CSN: Chip Select Not]
const byte address[6] = "00001";// 5 byte address of transmitter
char text[2];// array to store the character to be sent
void setup() {
  Serial.begin(9600);//start serial communication
  Serial.println("Tx Starting");//start transmission
  radio.begin();// begin the radio with default conditions
  radio.openWritingPipe(address);////open  pipe for transmission
  radio.setPALevel(RF24_PA_MIN);// SET PA level High(0 dBm)
  radio.setDataRate(RF24_250KBPS);//set data rate 250 kbps options are (1MBps,2MBps)
  radio.stopListening();// make radio transmitter ready to tarnsmitt.
  radio.powerUp();
  pinMode(buzz, OUTPUT);
  pinMode(button, INPUT);
  digitalWrite(button, HIGH);
  pinMode(joyX, INPUT);
  pinMode(joyY, INPUT);
  pinMode(button_up1, OUTPUT);
  digitalWrite(button_up1, HIGH);
  pinMode(button_down1, OUTPUT);
  digitalWrite(button_down1, HIGH);
  pinMode(button_left1, OUTPUT);
  digitalWrite(button_left1, HIGH);
  pinMode(button_right1, OUTPUT);
  digitalWrite(button_right1, HIGH);
  pinMode(fLED, OUTPUT);
  pinMode(rLED, OUTPUT);
  pinMode(lLED, OUTPUT);
  pinMode(tLED, OUTPUT);
  digitalWrite(buzz, HIGH);

}

void loop()
{
  read(); //read the value of joystick
  buzzer();//beep the buzzer


  //Depending on the position of the joystick, and the corresponding values from the two potentiometers the command is encoded into characters ff, ll, rr
  // which represent Forward,  Left, Right respectively.


  if (xValue >= 1020 && button_up == 1)
  {
    if (xValue > yValue)
    {
      text[0] = 'f';
      text[1] = 'f';
      send();
      digitalWrite(fLED, HIGH);
      delay(1000);
      digitalWrite(fLED, LOW);
    }
  }

  else if (xValue >= 1020 && button_up == 0 )
  {
    if (xValue > yValue)
    {
      text[0] = 's';
      text[1] = 'f';
      send();
      digitalWrite(fLED, HIGH);
      delay(300);
      digitalWrite(fLED, LOW);
    }
  }

  else if ( yValue >= 1020)
  {
    if (xValue < yValue)
    {
      text[0] = 'l';
      text[1] = 'l';
      send();
      digitalWrite(lLED, HIGH);
      delay(300);
      digitalWrite(lLED, LOW);
    }
  }
  else if ( yValue >= 1020 &&  button_left == 0 )
  {
    if (xValue < yValue)
    {
      text[0] = 's';
      text[1] = 'l';
      send();
      digitalWrite(lLED, HIGH);
      delay(300);
      digitalWrite(lLED, LOW);
    }
  }
  else if ( yValue <= 10)
  {
    text[0] = 'r';
    text[1] = 'r';;
    send();
    digitalWrite(rLED, HIGH);
    delay(300);
    digitalWrite(rLED, LOW);
  }
  else if ( yValue <= 10 &&  button_right == 0)
  {
    text[0] = 's';
    text[1] = 'r';;
    send();
    digitalWrite(rLED, HIGH);
    delay(300);
    digitalWrite(rLED, LOW);
  }
  else if ( xValue <= 10 )
  {
    text[0] = 's';
    text[1] = 's';;
    send();
  }

  else if (button_down == 0 )
  {
    text[0] = 'w';
    text[1] = 'd';;
    send();
    digitalWrite(fLED, HIGH);
    digitalWrite(lLED, HIGH);
    digitalWrite(rLED, HIGH);
    delay(100);
    digitalWrite(fLED, LOW);
    digitalWrite(lLED, LOW);
    digitalWrite(rLED, LOW);
  }
}
/*
  ▪ * Function Name: void send()
  ▪ * Input: none
  ▪ * Output: none
  ▪ * Logic: this function are use for send the data toword thr receiver
  ▪ * Example Call: send()
  ▪ */
void send()
{
  bool ack;  //initilize the variable to store the statuse of data send or not
  ack = radio.write(&text, sizeof(text));// sends data to receiver
  Serial.println(text);
  if (ack) //if data is succesfully transmitted then ack =1 and transmision LEd is on else off
  {
    Serial.println("tx succesful");
    digitalWrite(tLED, HIGH);

  }
  else {
    Serial.println("  Tx failed");
    digitalWrite(tLED, LOW);
  }
}
/*
  ▪ * Function Name:void read()
  ▪ * Input: none
  ▪ * Output:none
  ▪ * Logic:this function read the statuse of joystick module and push buttons
  ▪ * Example Call:read();
  ▪ */

void read()
{
  button_up = digitalRead(button_up1); //read state of the up Button
  button_down = digitalRead(button_down1); //read state of the down Button
  button_left = digitalRead(button_left1); //read state of the left Button
  button_right = digitalRead(button_right1); //read state of the right Button
  xValue = analogRead(joyX);// read the analog value of Horizontal axis Potentiometer
  yValue = analogRead(joyY);// read the analog value of Vertical axis Potentiometer
  buttonState = digitalRead(button); //read state of the Button
}
/*
   Function Name:void buzzer()
   Input: none
   Output:none
   Logic: this function turn on the buzzer at starting the run and end of the run
   Example Call:buzzer();
*/

void buzzer()
{

  if (buttonState == 0) //if the bush button of joystick is press for start of the run
  {
    if (count == 0)//turn on the buzzer for 2sec
    {
      digitalWrite(buzz, 0);
      delay(2000);
      digitalWrite(buzz, 1);
      count++;
    }
    else if (count == 1)//turn on the buzzer for 3sec for end of the run
    {
      digitalWrite(buzz, 0);
      delay(3000);
      digitalWrite(buzz, 1);
      count++;
    }
  }

}
